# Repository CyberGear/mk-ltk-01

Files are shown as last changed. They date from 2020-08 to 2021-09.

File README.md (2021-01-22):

# Bleeding Charcoal (mk-ltk-01)

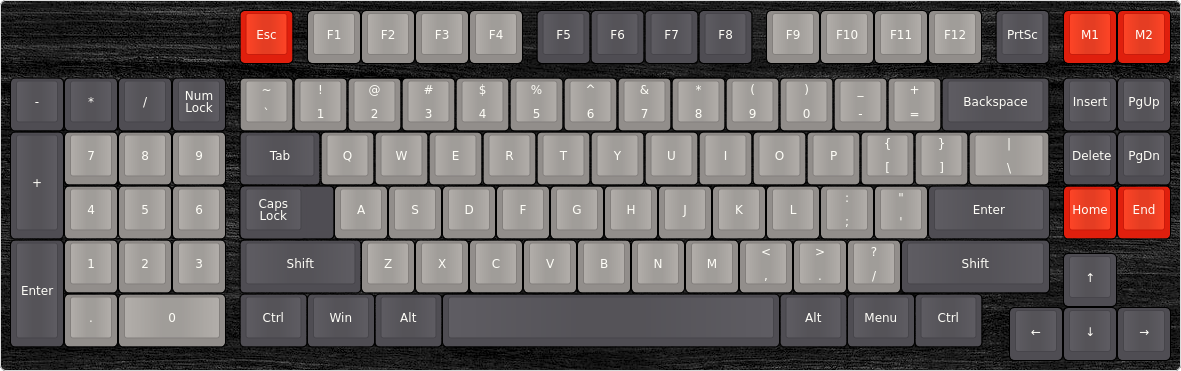
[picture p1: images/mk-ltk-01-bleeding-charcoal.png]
visualisation

[First Idea](./images/mk-ltk-01.png)

## Details
* **Keeb**: Black steel dust painted plate, sandwich case, stained plywood
* **Kaycaps**: [Aliexpress ones](https://www.aliexpress.com/item/1005001285224963.html?spm=a2g0s.9042311.0.0.27424c4dBEbhVW) also custom painted for accent caps
* **Switches**: Gateron brown, Lubed with Krytox 205g0, and filmed.
* **Stabs**: [Aliexpress ones](https://www.aliexpress.com/item/10000249766414.html?spm=a2g0s.9042311.0.0.27424c4dtrbYE2) lubed and cliped a lot :D

## Initial Requirements
* As low prifile as possible
* Reasonable price around 100€ (failed! 170€)
* NOT flat profile keycaps
* Tactile
* Left side num pad
* Stardart layout (keycaps wise)
* Make most space for mouse withour loosing functionality (on the right)

## Tools
* http://www.keyboard-layout-editor.com
* http://builder.swillkb.com/
* https://kbfirmware.com/
* https://noroadsleft.github.io/kbf_qmk_converter/

## Decisions made
* Sandwich case (stained plywood and painted black steel)
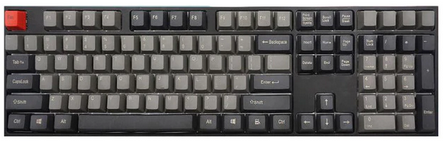
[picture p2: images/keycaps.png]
OEM keycaps
*  
  Unfortunatelly to high for low profile switches
* Diodes 1N4148
* Gateron Brown
* Plate mounted stabs from Aliexpress
* Krytox GPL 205 G0
* Switch Films
* Teensy 2.0++

## Progress

Metal parts :) 

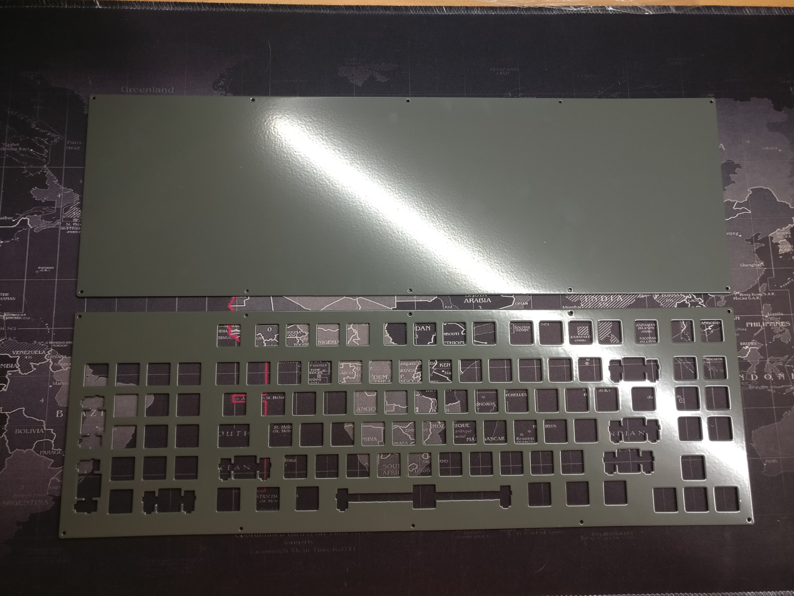
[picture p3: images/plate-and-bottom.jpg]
Plates


Put foam for sound dampening (legacy acrylic frame)

With foam

Plywood case V1

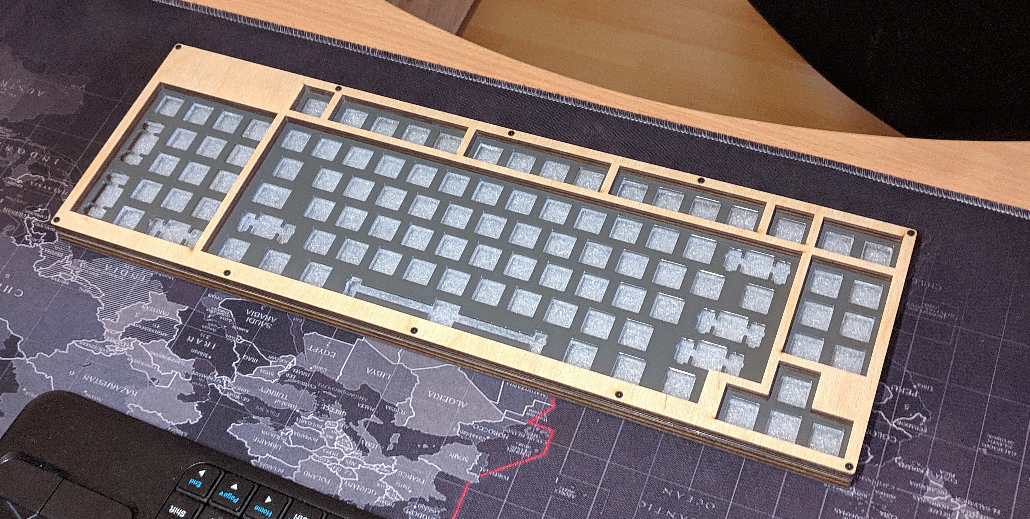
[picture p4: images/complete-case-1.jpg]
Complete case !


Wrist rest :D 

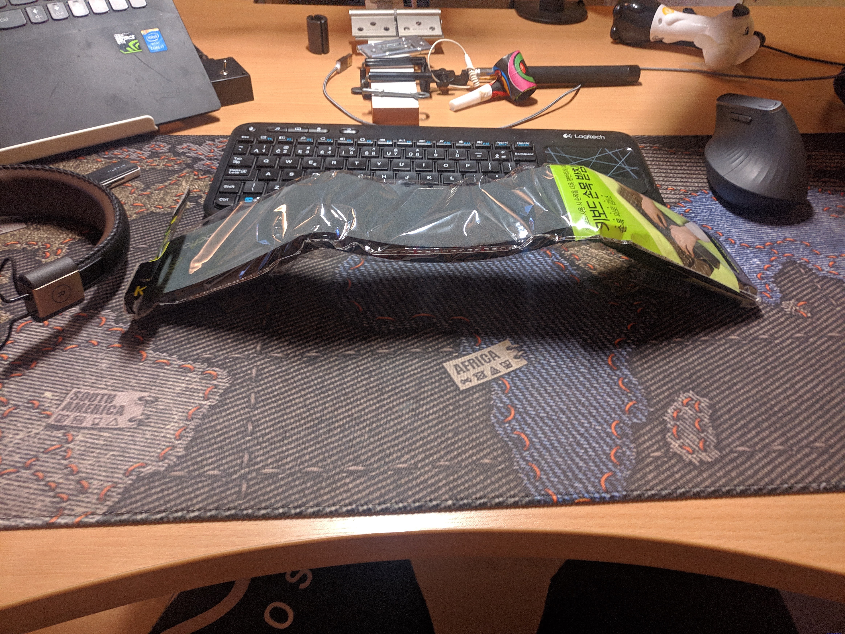
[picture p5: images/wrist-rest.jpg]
Wrist rest


New desk mat

Desk mat

Lubing and filling switches

Lube progress

Fit test "naked"

Nude fit test

Fit test full case

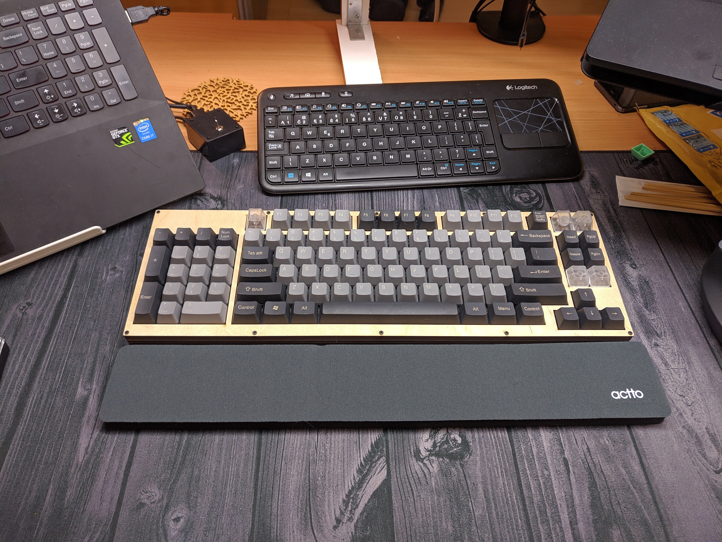
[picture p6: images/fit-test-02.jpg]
Fit test


Screwless top

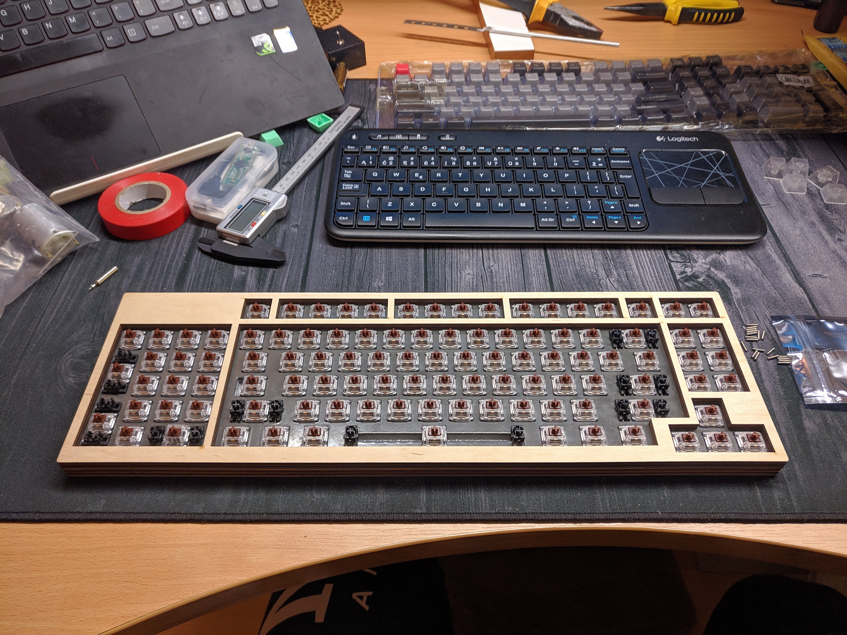
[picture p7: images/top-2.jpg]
Top 2


USB type-C cutout

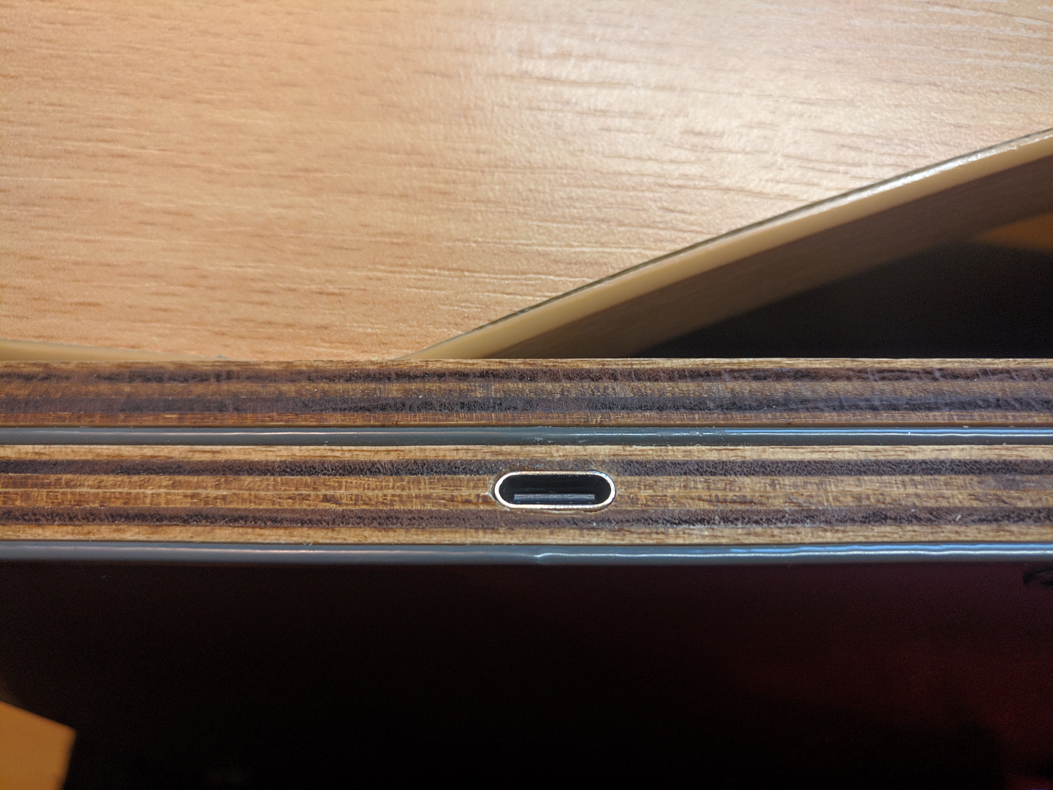
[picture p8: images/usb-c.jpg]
usb-c


Switch matrix ([mirrored](./images/switch-matrix-mirror.png))

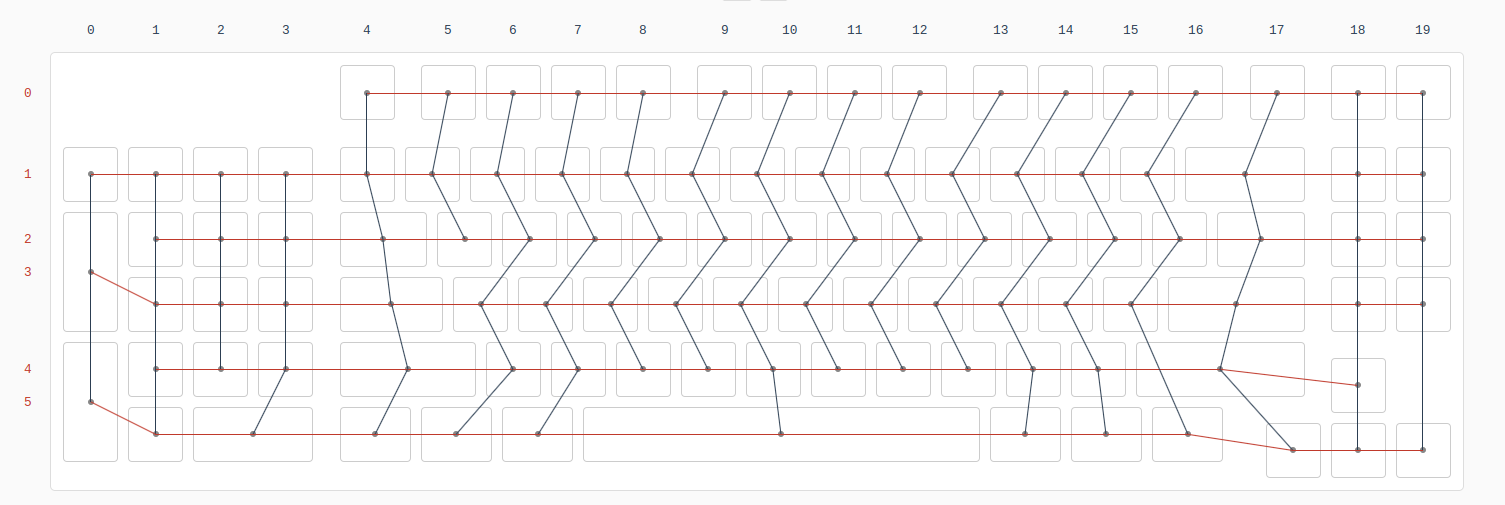
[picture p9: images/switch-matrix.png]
Switch matrix


Wiring

wiring

Usb type-c Integration

usb type-c

More foam

more foam

Total foam

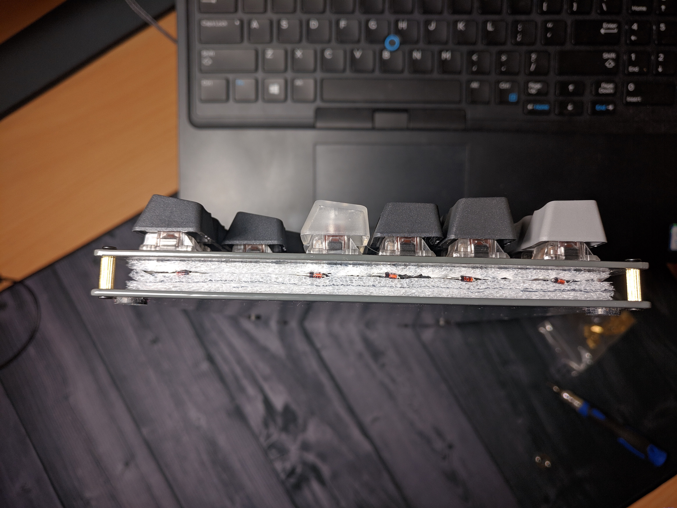
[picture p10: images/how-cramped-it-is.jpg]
total foam


Suprisingly Simple Adjustable Legs

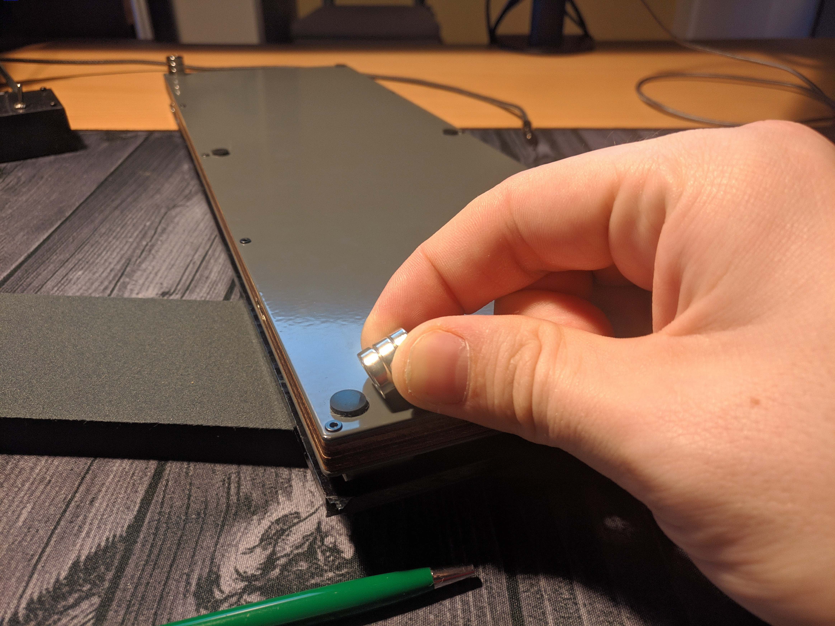
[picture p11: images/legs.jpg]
legs


Custom Spray Painted Keycaps

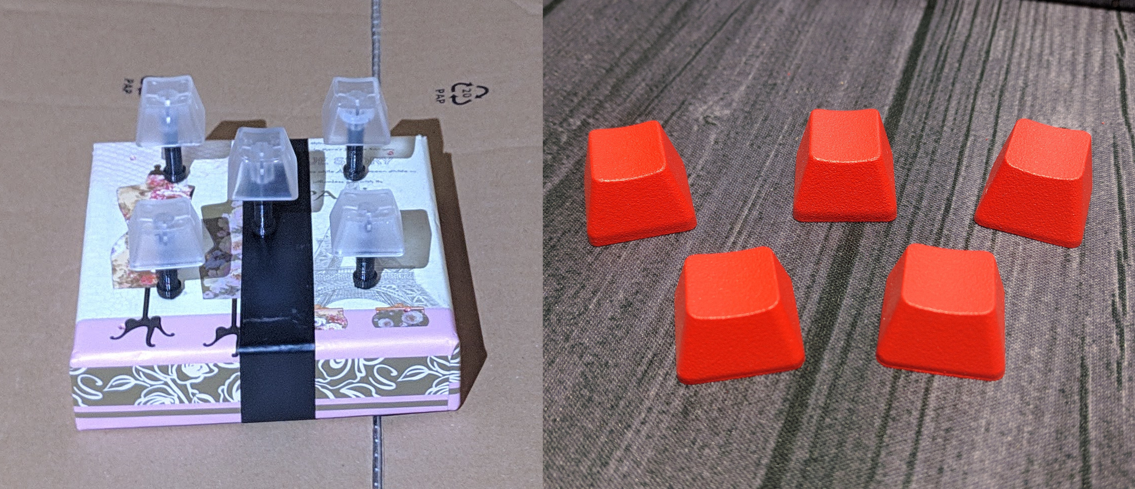
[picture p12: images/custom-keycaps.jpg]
Keycaps


Stained plywood finish

finish

Wire

wire

RESULT

Keeb

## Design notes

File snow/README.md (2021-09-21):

# Kit contents

1. *Plate* - dust painted aluminum
2. *PCB* - also white
3. *Bottom plate* - dust painted steel
4. *USB socket* - fits in one of those cuts in PCB
5. *Socket soldering template* - to help to solder it straight
6. *4 small rubber feet*

# Features

1. Left ten keys layout (southpaw layout) 
2. Intelligently mirrored num pan layout 
3. PCB features:
    1. Supports MX switches 
    2. Supports kailh hot-swappable sockets 
    3. Supports thru-hole diods 
    4. Supports surface mount diodes 

# Required additional parts

1. Teensy ® ++ 2.0
2. Full set of keycaps (recommend flat layout, because of 'Home' and 'End' possitions)
4. Full set of stabilizers 
    1. Plate mounted works out of the box
    2. PCB mounted requires addition filing of switch plate :/ 
5. 108 x MX switches
6. 108 x 1N4148 diods
7. 20 x M2 screws
8. 10 x 9mm M2 spacers (if You remove mini USB from teensy)
9. USB Type-C cable

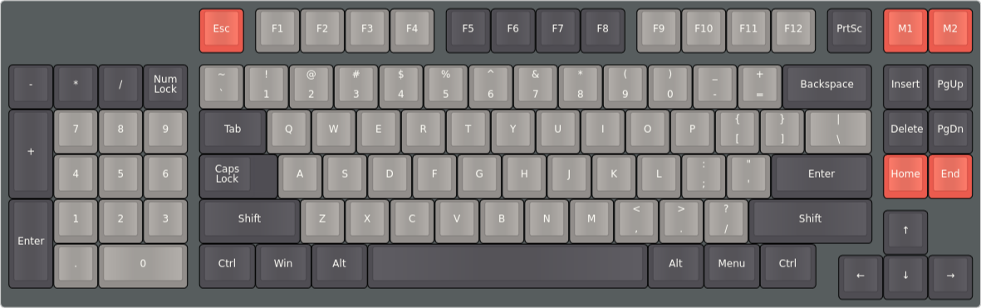
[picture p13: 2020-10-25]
images/mk-ltk-01.png

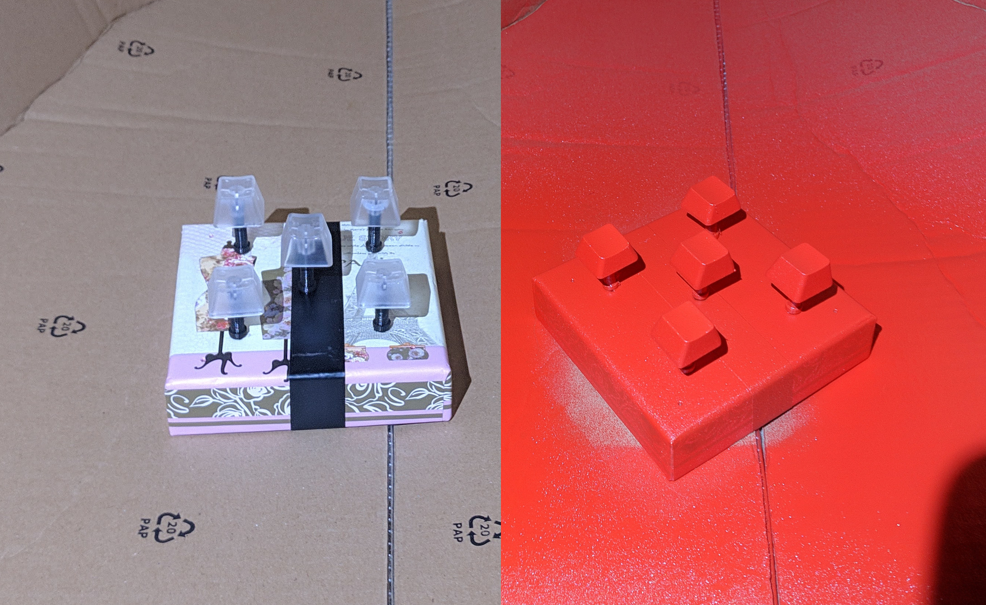
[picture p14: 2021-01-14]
images/keycap-paint-job.jpg

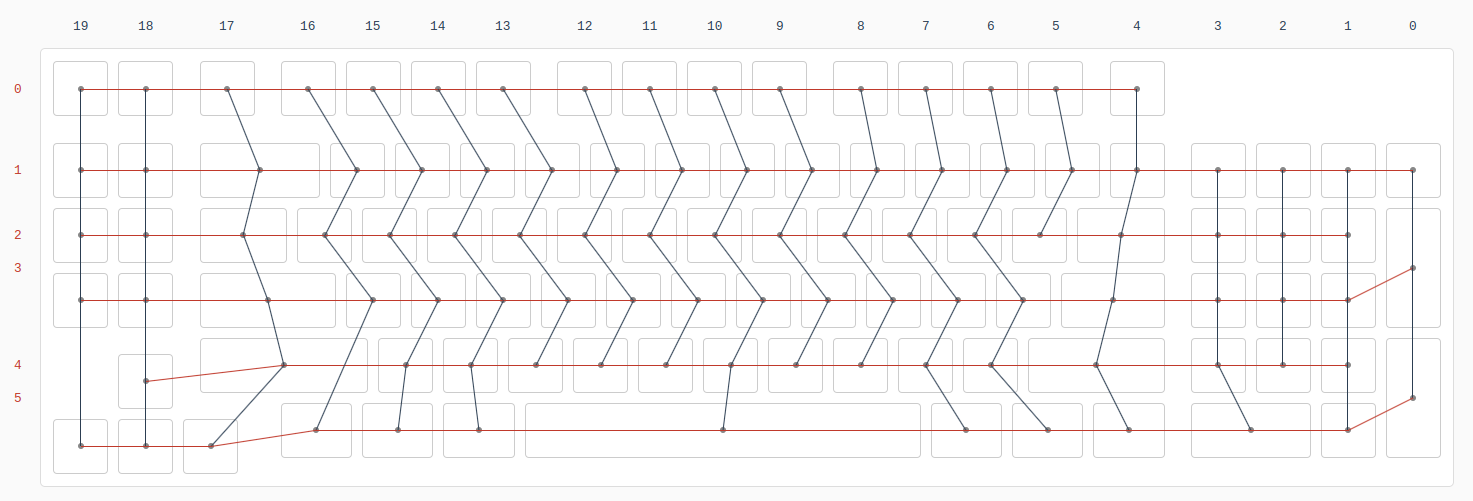
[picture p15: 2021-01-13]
images/switch-matrix-mirror.png

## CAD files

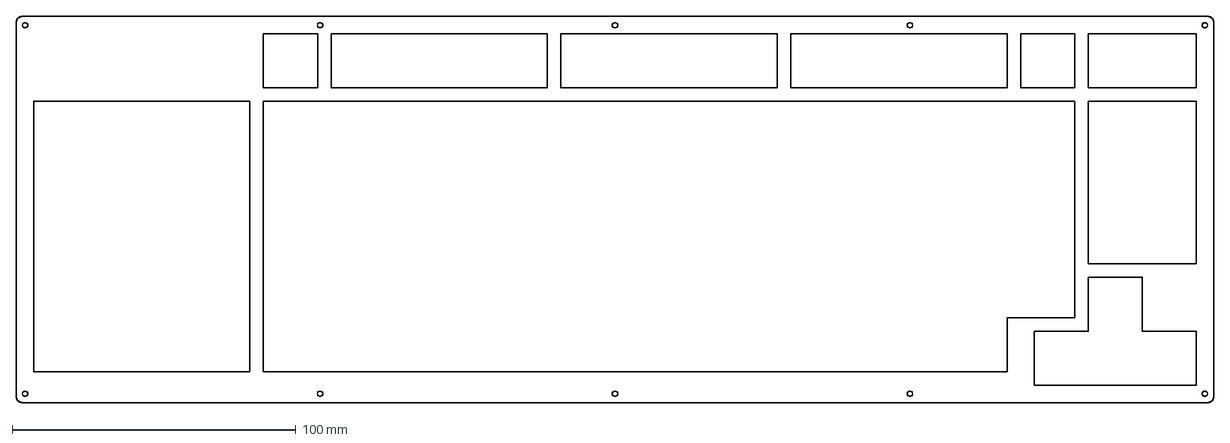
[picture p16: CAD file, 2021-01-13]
sandwich case/mk-ltk-01_top_02_with_holes.dxf
421.8 x 136.0 mm

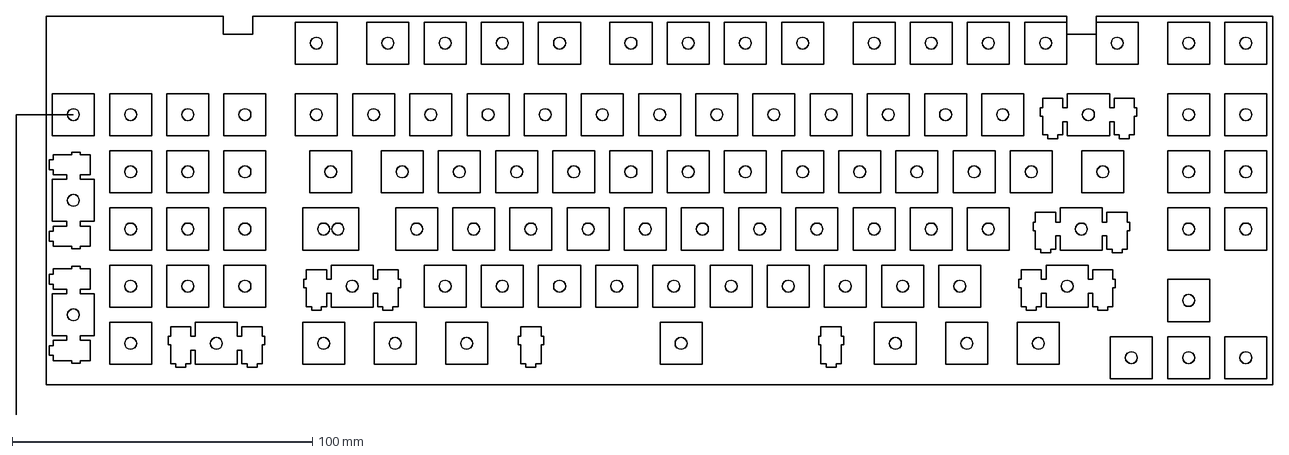
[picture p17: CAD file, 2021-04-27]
snow/onesided-palte.dxf
418.6 x 132.8 mm

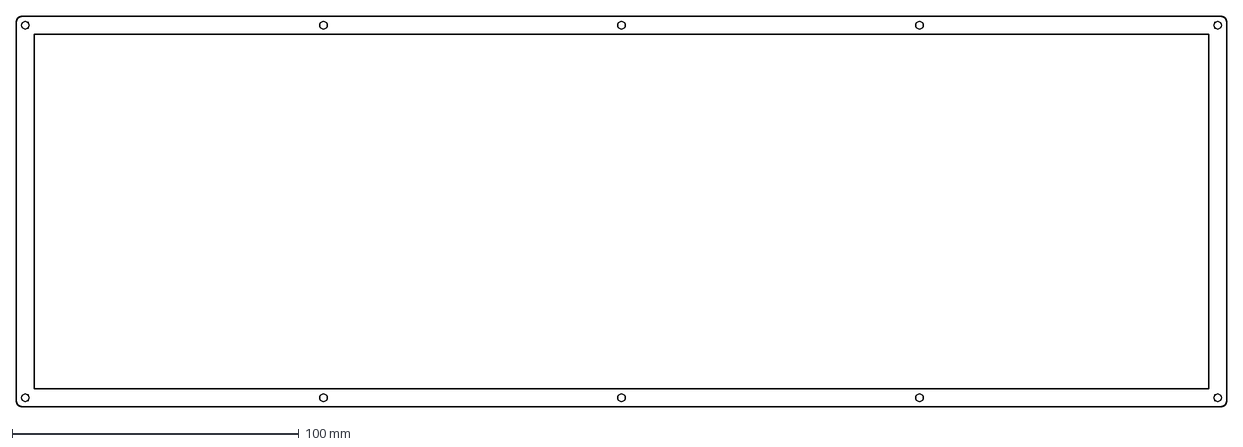
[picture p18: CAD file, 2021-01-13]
sandwich case/mk-ltk-01_closed_02.dxf
421.8 x 136.0 mm

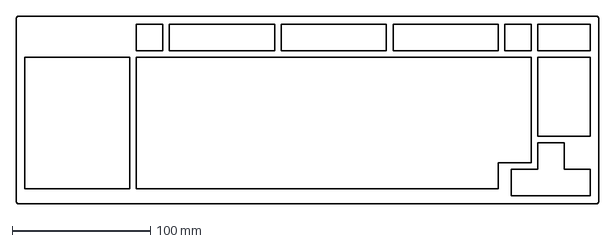
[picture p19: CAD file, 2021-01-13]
sandwich case/mk-ltk-01_top_02.dxf
421.8 x 136.0 mm

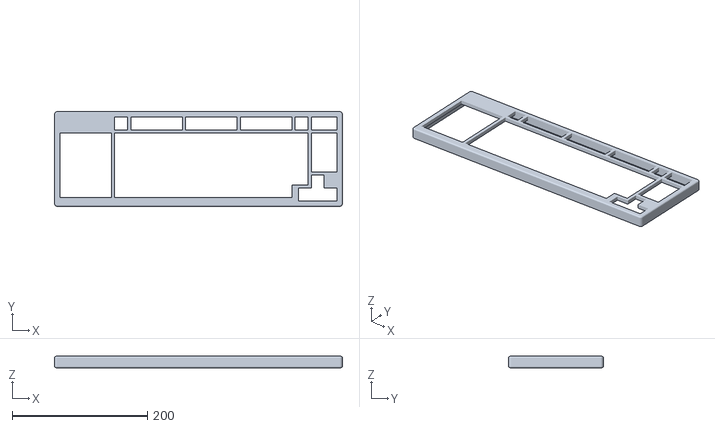
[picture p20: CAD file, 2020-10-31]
sandwich case/mk-ltk-01_top.stl
425.6 x 139.8 x 17.0

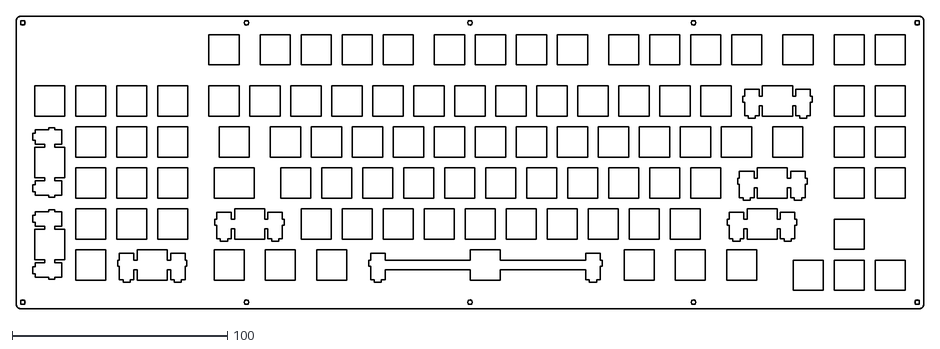
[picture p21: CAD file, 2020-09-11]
sandwich case/mk-ltk-01_switch.dxf
421.6 x 135.8

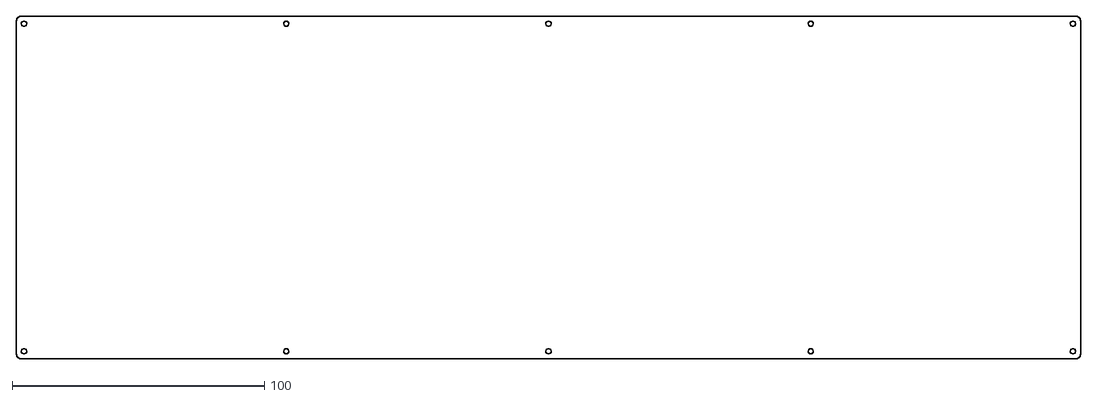
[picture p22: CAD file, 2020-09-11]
sandwich case/mk-ltk-01_bottom.dxf
421.6 x 135.8

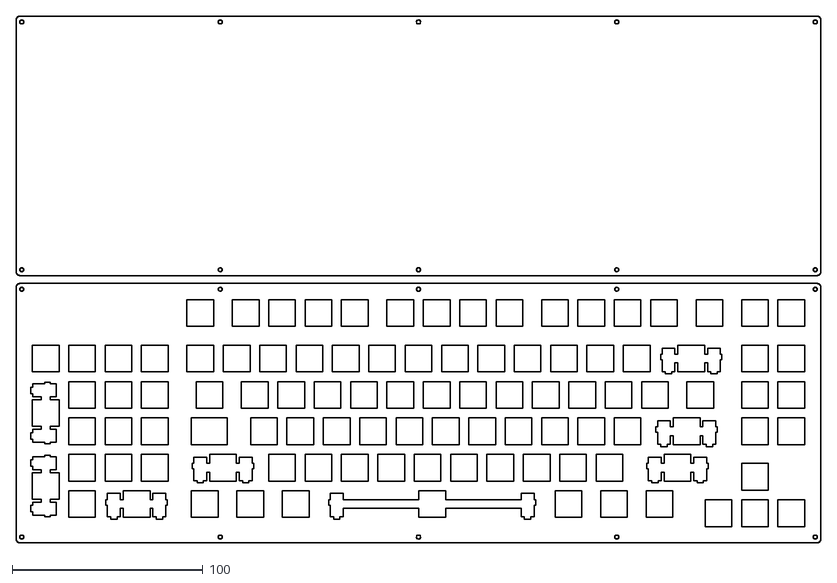
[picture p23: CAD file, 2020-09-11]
sandwich case/mk-ltk-01_switch_bottom.dxf
421.6 x 275.8

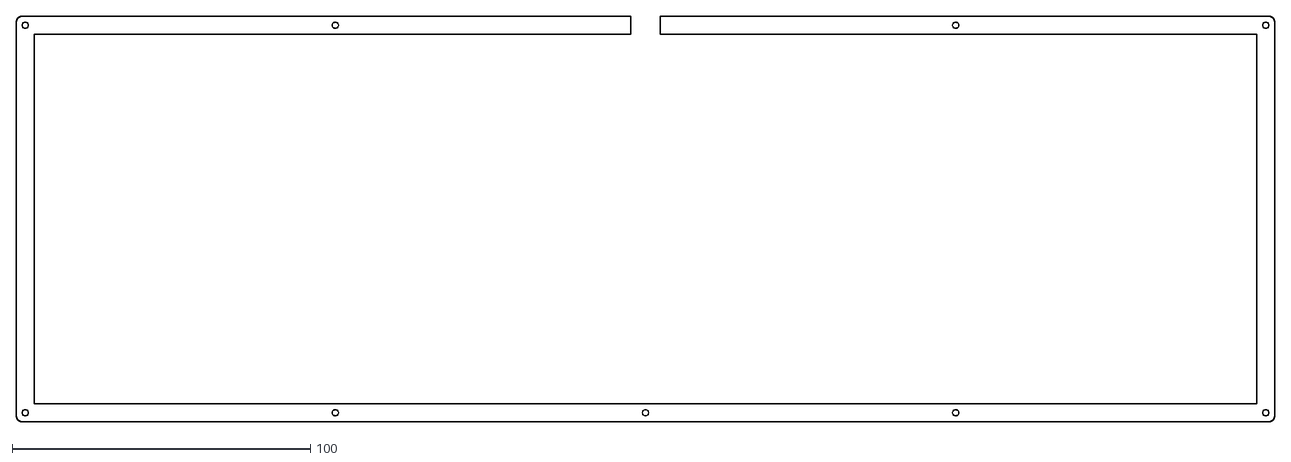
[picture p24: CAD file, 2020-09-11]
sandwich case/mk-ltk-01_open.dxf
421.6 x 135.8

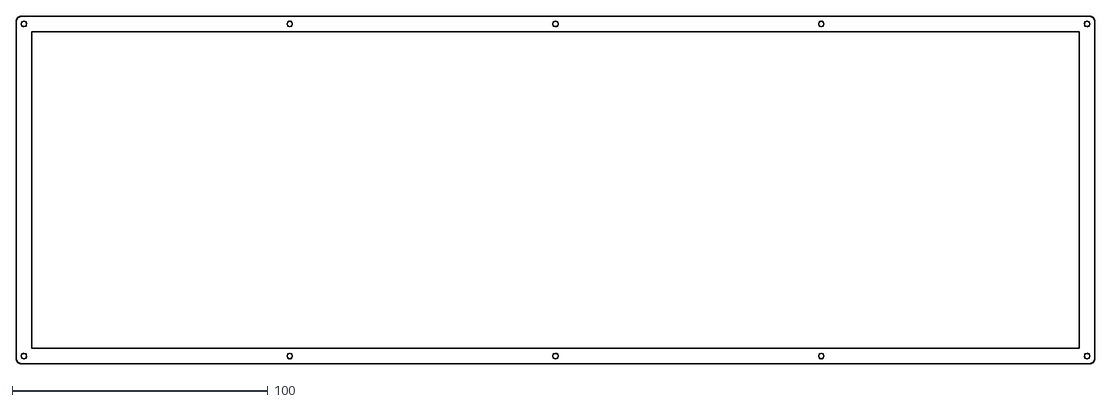
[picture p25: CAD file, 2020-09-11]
sandwich case/mk-ltk-01_closed.dxf
421.6 x 135.8

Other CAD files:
sandwich case/mk-ltk-01_case-cover.FCStd
sandwich case/mk-ltk-01_top.dxf

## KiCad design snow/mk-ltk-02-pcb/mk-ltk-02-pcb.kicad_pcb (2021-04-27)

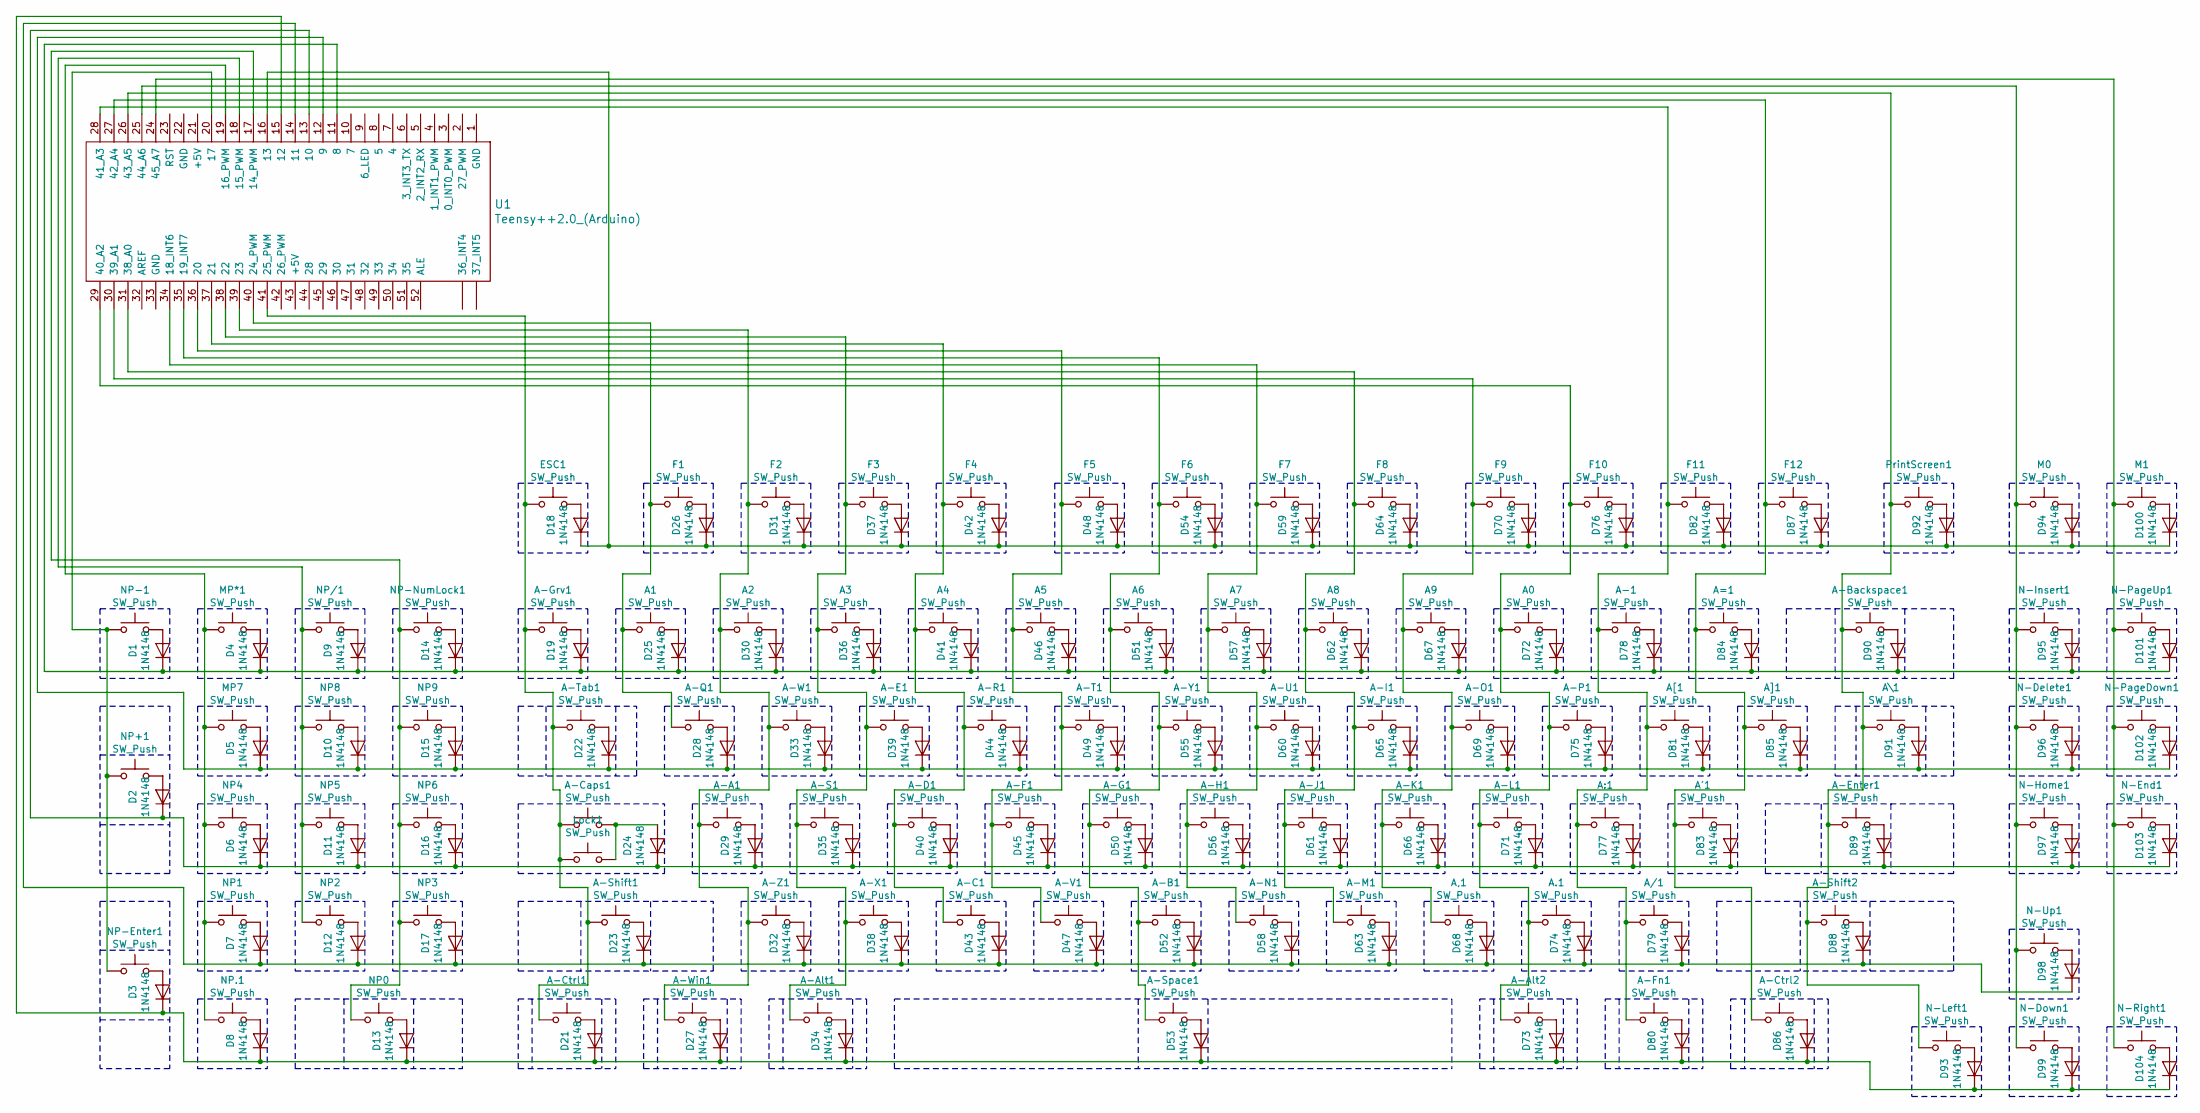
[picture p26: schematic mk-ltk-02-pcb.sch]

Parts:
A0, A1, A2, A3, A4, A5, A6, A7, A8, A9, A.1: SW_Push; Kailh_socket_MX_optional
A'1: SW_Push; Kailh_socket_MX_optional
A,1: SW_Push; Kailh_socket_MX_optional
A-1: SW_Push; Kailh_socket_MX_optional
A-A1: SW_Push; Kailh_socket_MX_optional
A-Alt1, A-Alt2: SW_Push; Kailh_socket_MX_optional
A-B1: SW_Push; Kailh_socket_MX_optional
A-Backspace1: SW_Push; Kailh_socket_MX_optional
A-C1: SW_Push; Kailh_socket_MX_optional
A-Caps1: SW_Push; Kailh_socket_MX_optional
A-Ctrl1, A-Ctrl2: SW_Push; Kailh_socket_MX_optional
A-D1: SW_Push; Kailh_socket_MX_optional
A-E1: SW_Push; Kailh_socket_MX_optional
A-Enter1: SW_Push; Kailh_socket_MX_optional
A-F1: SW_Push; Kailh_socket_MX_optional
A-Fn1: SW_Push; Kailh_socket_MX_optional
A-G1: SW_Push; Kailh_socket_MX_optional
A-Grv1: SW_Push; Kailh_socket_MX_optional
A-H1: SW_Push; Kailh_socket_MX_optional
A-I1: SW_Push; Kailh_socket_MX_optional
A-J1: SW_Push; Kailh_socket_MX_optional
A-K1: SW_Push; Kailh_socket_MX_optional
A-L1: SW_Push; Kailh_socket_MX_optional
A-M1: SW_Push; Kailh_socket_MX_optional
A-N1: SW_Push; Kailh_socket_MX_optional
A-O1: SW_Push; Kailh_socket_MX_optional
A-P1: SW_Push; Kailh_socket_MX_optional
A-Q1: SW_Push; Kailh_socket_MX_optional
A-R1: SW_Push; Kailh_socket_MX_optional
A-S1: SW_Push; Kailh_socket_MX_optional
A-Shift1, A-Shift2: SW_Push; Kailh_socket_MX_optional
A-Space1: SW_Push; Kailh_socket_MX_optional
A-T1: SW_Push; Kailh_socket_MX_optional
A-Tab1: SW_Push; Kailh_socket_MX_optional
A-U1: SW_Push; Kailh_socket_MX_optional
A-V1: SW_Push; Kailh_socket_MX_optional
A-W1: SW_Push; Kailh_socket_MX_optional
A-Win1: SW_Push; Kailh_socket_MX_optional
A-X1: SW_Push; Kailh_socket_MX_optional
A-Y1: SW_Push; Kailh_socket_MX_optional
A-Z1: SW_Push; Kailh_socket_MX_optional
A/1: SW_Push; Kailh_socket_MX_optional
A:1: SW_Push; Kailh_socket_MX_optional
A=1: SW_Push; Kailh_socket_MX_optional
A[1: SW_Push; Kailh_socket_MX_optional
A\1: SW_Push; Kailh_socket_MX_optional
A]1: SW_Push; Kailh_socket_MX_optional
D1, D2, D3, D4, D5, D6, D7, D8, D9, D10, D11, D12, D13, D14, D15, D16, D17, D18, D19, D21, D22, D23, D24, D25, D26, D27, D28, D29, D30, D31, D32, D33, D34, D35, D36, D37, D38, D39, D40, D41, D42, D43, D44, D45, D46, D47, D48, D49, D50, D51, D52, D53, D54, D55, D56, D57, D58, D59, D60, D61, D62, D63, D64, D65, D66, D67, D68, D69, D70, D71, D72, D73, D74, D75, D76, D77, D78, D79, D80, D81, D82, D83, D84, D85, D86, D87, D88, D89, D90, D91, D92, D93, D94, D95, D96, D97, D98, D99, D100, D101, D102, D103, D104: 1N4148; Diode-smd-tht
ESC1: SW_Push; Kailh_socket_MX_optional
F1, F2, F3, F4, F5, F6, F7, F8, F9, F10, F11, F12: SW_Push; Kailh_socket_MX_optional
Lock1: SW_Push; Kailh_socket_MX_optional
M0, M1: SW_Push; Kailh_socket_MX_optional
MP7: SW_Push; Kailh_socket_MX_optional
MP*1: SW_Push; Kailh_socket_MX_optional
N-Delete1: SW_Push; Kailh_socket_MX_optional
N-Down1: SW_Push; Kailh_socket_MX_optional
N-End1: SW_Push; Kailh_socket_MX_optional
N-Home1: SW_Push; Kailh_socket_MX_optional
N-Insert1: SW_Push; Kailh_socket_MX_optional
N-Left1: SW_Push; Kailh_socket_MX_optional
N-PageDown1: SW_Push; Kailh_socket_MX_optional
N-PageUp1: SW_Push; Kailh_socket_MX_optional
N-Right1: SW_Push; Kailh_socket_MX_optional
N-Up1: SW_Push; Kailh_socket_MX_optional
NP0, NP1, NP2, NP3, NP4, NP5, NP6, NP8, NP9, NP.1: SW_Push; Kailh_socket_MX_optional
NP+1: SW_Push; Kailh_socket_MX_optional
NP-1: SW_Push; Kailh_socket_MX_optional
NP-Enter1: SW_Push; Kailh_socket_MX_optional
NP-NumLock1: SW_Push; Kailh_socket_MX_optional
NP/1: SW_Push; Kailh_socket_MX_optional
PrintScreen1: SW_Push; Kailh_socket_MX_optional
U1: Teensy++2.0_(Arduino); Teensy2.0++

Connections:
unnamed: A0.2, D72.2 (A)
unnamed: A1.2, D25.2 (A)
unnamed: A2.2, D30.2 (A)
unnamed: A3.2, D36.2 (A)
unnamed: A4.2, D41.2 (A)
unnamed: A5.2, D46.2 (A)
unnamed: A6.2, D51.2 (A)
unnamed: A7.2, D57.2 (A)
unnamed: A8.2, D62.2 (A)
unnamed: A9.2, D67.2 (A)
unnamed: A'1.1, A-Ctrl2.1, A=1.1, A]1.1, F12.1, U1.27 (42_A4)
unnamed: A'1.2, D83.2 (A)
unnamed: A9.1, A,1.1, A-K1.1, A-O1.1, F9.1, U1.30 (39_A1)
unnamed: A,1.2, D68.2 (A)
unnamed: A-1.1, A-Fn1.1, A/1.1, A:1.1, A[1.1, F11.1, U1.28 (41_A3)
unnamed: A-1.2, D78.2 (A)
unnamed: A2.1, A-A1.1, A-W1.1, A-Win1.1, A-Z1.1, F2.1, U1.39 (23)
unnamed: A-A1.2, D29.2 (A)
unnamed: A3.1, A-Alt1.1, A-E1.1, A-S1.1, A-X1.1, F3.1, U1.38 (22)
unnamed: A-Alt1.2, D34.2 (A)
unnamed: A0.1, A-Alt2.1, A-L1.1, A-P1.1, A.1.1, F10.1, U1.29 (40_A2)
unnamed: A-Alt2.2, D73.2 (A)
unnamed: A6.1, A-B1.1, A-G1.1, A-Space1.1, A-Y1.1, F6.1, U1.35 (19_INT7)
unnamed: A-B1.2, D52.2 (A)
unnamed: A-Backspace1.1, A-Enter1.1, A-Shift2.1, A\1.1, N-Left1.1, PrintScreen1.1, U1.26 (43_A5)
unnamed: A-Backspace1.2, D90.2 (A)
unnamed: A4.1, A-C1.1, A-D1.1, A-R1.1, F4.1, U1.37 (21)
unnamed: A-C1.2, D43.2 (A)
unnamed: A-Caps1.1, A-Ctrl1.1, A-Grv1.1, A-Shift1.1, A-Tab1.1, ESC1.1, Lock1.1, U1.41 (25_PWM)
unnamed: A-Caps1.2, D24.2 (A), Lock1.2
unnamed: A-Ctrl1.2, D21.2 (A)
unnamed: A-Ctrl2.2, D86.2 (A)
unnamed: A-D1.2, D40.2 (A)
unnamed: A-E1.2, D39.2 (A)
unnamed: A-Enter1.2, D89.2 (A)
unnamed: A5.1, A-F1.1, A-T1.1, A-V1.1, F5.1, U1.36 (20)
unnamed: A-F1.2, D45.2 (A)
unnamed: A-Fn1.2, D80.2 (A)
unnamed: A-G1.2, D50.2 (A)
unnamed: A-Grv1.2, D19.2 (A)
unnamed: A7.1, A-H1.1, A-N1.1, A-U1.1, F7.1, U1.34 (18_INT6)
unnamed: A-H1.2, D56.2 (A)
unnamed: A8.1, A-I1.1, A-J1.1, A-M1.1, F8.1, U1.31 (38_A0)
unnamed: A-I1.2, D65.2 (A)
unnamed: A-J1.2, D61.2 (A)
unnamed: A-K1.2, D66.2 (A)
unnamed: A-L1.2, D71.2 (A)
unnamed: A-M1.2, D63.2 (A)
unnamed: A-N1.2, D58.2 (A)
unnamed: A-O1.2, D69.2 (A)
unnamed: A-P1.2, D75.2 (A)
unnamed: A1.1, A-Q1.1, F1.1, U1.40 (24_PWM)
unnamed: A-Q1.2, D28.2 (A)
unnamed: A-R1.2, D44.2 (A)
unnamed: A-S1.2, D35.2 (A)
unnamed: A-Shift1.2, D23.2 (A)
unnamed: A-Shift2.2, D88.2 (A)
unnamed: A-Space1.2, D53.2 (A)
unnamed: A-T1.2, D49.2 (A)
unnamed: A-Tab1.2, D22.2 (A)
unnamed: A-U1.2, D60.2 (A)
unnamed: A-V1.2, D47.2 (A)
unnamed: A-W1.2, D33.2 (A)
unnamed: A-Win1.2, D27.2 (A)
unnamed: A-X1.2, D38.2 (A)
unnamed: A-Y1.2, D55.2 (A)
unnamed: A-Z1.2, D32.2 (A)
unnamed: A.1.2, D74.2 (A)
unnamed: A/1.2, D79.2 (A)
unnamed: A:1.2, D77.2 (A)
unnamed: A=1.2, D84.2 (A)
unnamed: A[1.2, D81.2 (A)
unnamed: A\1.2, D91.2 (A)
unnamed: A]1.2, D85.2 (A)
unnamed: D1.1 (K), D4.1 (K), D9.1 (K), D14.1 (K), D19.1 (K), D25.1 (K), D30.1 (K), D36.1 (K), D41.1 (K), D46.1 (K), D51.1 (K), D57.1 (K), D62.1 (K), D67.1 (K), D72.1 (K), D78.1 (K), D84.1 (K), D90.1 (K), D95.1 (K), D101.1 (K), U1.11 (8)
unnamed: D1.2 (A), NP-1.2
unnamed: D2.2 (A), NP+1.2
unnamed: D3.2 (A), NP-Enter1.2
unnamed: D4.2 (A), MP*1.2
unnamed: D5.2 (A), MP7.2
unnamed: D6.2 (A), NP4.2
unnamed: D7.2 (A), NP1.2
unnamed: D8.2 (A), NP.1.2
unnamed: D9.2 (A), NP/1.2
unnamed: D5.1 (K), D10.1 (K), D15.1 (K), D22.1 (K), D28.1 (K), D33.1 (K), D39.1 (K), D44.1 (K), D49.1 (K), D55.1 (K), D60.1 (K), D65.1 (K), D69.1 (K), D75.1 (K), D81.1 (K), D85.1 (K), D91.1 (K), D96.1 (K), D102.1 (K), U1.12 (9)
unnamed: D10.2 (A), NP8.2
unnamed: D11.2 (A), NP5.2
unnamed: D7.1 (K), D12.1 (K), D17.1 (K), D23.1 (K), D32.1 (K), D38.1 (K), D43.1 (K), D47.1 (K), D52.1 (K), D58.1 (K), D63.1 (K), D68.1 (K), D74.1 (K), D79.1 (K), D88.1 (K), D98.1 (K), U1.14 (11)
unnamed: D12.2 (A), NP2.2
unnamed: D13.2 (A), NP0.2
unnamed: D14.2 (A), NP-NumLock1.2
unnamed: D15.2 (A), NP9.2
unnamed: D16.2 (A), NP6.2
unnamed: D17.2 (A), NP3.2
unnamed: D18.2 (A), ESC1.2
unnamed: D26.2 (A), F1.2
unnamed: D31.2 (A), F2.2
unnamed: D37.2 (A), F3.2
unnamed: D42.2 (A), F4.2
unnamed: D48.2 (A), F5.2
unnamed: D54.2 (A), F6.2
unnamed: D59.2 (A), F7.2
unnamed: D64.2 (A), F8.2
unnamed: D70.2 (A), F9.2
unnamed: D76.2 (A), F10.2
unnamed: D82.2 (A), F11.2
unnamed: D87.2 (A), F12.2
unnamed: D92.2 (A), PrintScreen1.2
unnamed: D93.2 (A), N-Left1.2
unnamed: D94.2 (A), M0.2
unnamed: D95.2 (A), N-Insert1.2
unnamed: D96.2 (A), N-Delete1.2
unnamed: D97.2 (A), N-Home1.2
unnamed: D98.2 (A), N-Up1.2
unnamed: D99.2 (A), N-Down1.2
unnamed: D18.1 (K), D26.1 (K), D31.1 (K), D37.1 (K), D42.1 (K), D48.1 (K), D54.1 (K), D59.1 (K), D64.1 (K), D70.1 (K), D76.1 (K), D82.1 (K), D87.1 (K), D92.1 (K), D94.1 (K), D100.1 (K), U1.16 (13)
unnamed: D100.2 (A), M1.2
unnamed: D101.2 (A), N-PageUp1.2
unnamed: D102.2 (A), N-PageDown1.2
unnamed: D2.1 (K), D6.1 (K), D11.1 (K), D16.1 (K), D24.1 (K), D29.1 (K), D35.1 (K), D40.1 (K), D45.1 (K), D50.1 (K), D56.1 (K), D61.1 (K), D66.1 (K), D71.1 (K), D77.1 (K), D83.1 (K), D89.1 (K), D97.1 (K), D103.1 (K), U1.13 (10)
unnamed: D103.2 (A), N-End1.2
unnamed: D3.1 (K), D8.1 (K), D13.1 (K), D21.1 (K), D27.1 (K), D34.1 (K), D53.1 (K), D73.1 (K), D80.1 (K), D86.1 (K), D93.1 (K), D99.1 (K), D104.1 (K), U1.15 (12)
unnamed: D104.2 (A), N-Right1.2
unnamed: M0.1, N-Delete1.1, N-Down1.1, N-Home1.1, N-Insert1.1, N-Up1.1, U1.25 (44_A6)
unnamed: M1.1, N-End1.1, N-PageDown1.1, N-PageUp1.1, N-Right1.1, U1.24 (45_A7)
unnamed: MP7.1, MP*1.1, NP1.1, NP4.1, NP.1.1, U1.19 (16_PWM)
unnamed: NP+1.1, NP-1.1, NP-Enter1.1, U1.20 (17)
unnamed: NP0.1, NP3.1, NP6.1, NP9.1, NP-NumLock1.1, U1.17 (14_PWM)
unnamed: NP2.1, NP5.1, NP8.1, NP/1.1, U1.18 (15_PWM)

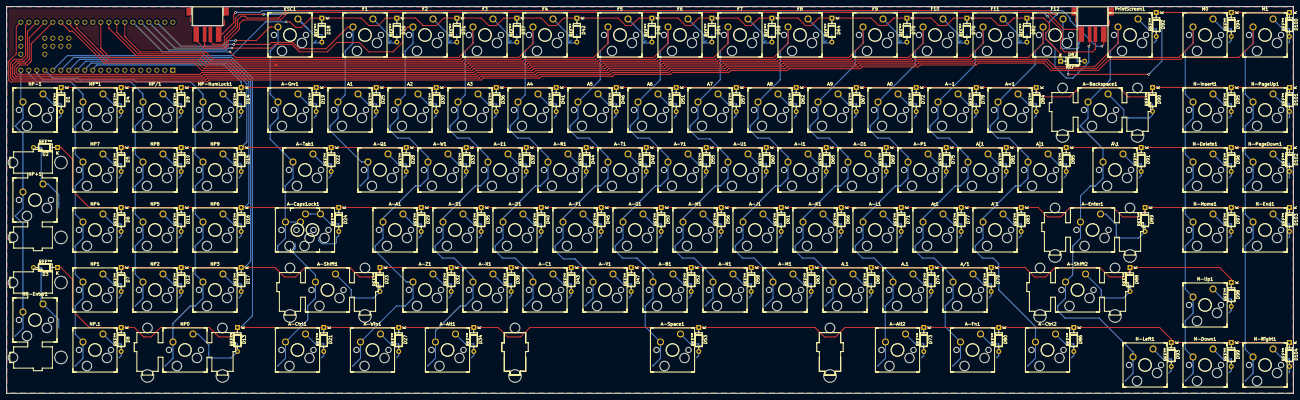
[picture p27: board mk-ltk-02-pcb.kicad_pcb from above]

Board: 2 copper layers, 408.5 x 122.8 mm, 208 parts (1 on the bottom side), 129 nets.

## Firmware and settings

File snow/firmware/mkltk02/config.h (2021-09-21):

/* Copyright 2021 REPLACE_WITH_YOUR_NAME
 *
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
 * You should have received a copy of the GNU General Public License
 * along with this program.  If not, see <http://www.gnu.org/licenses/>.
 */

#pragma once

#include "config_common.h"

/* USB Device descriptor parameter */
#define VENDOR_ID       0xFEED
#define PRODUCT_ID      0x0000
#define DEVICE_VER      0x0001
#define MANUFACTURER    CyberGear
#define PRODUCT         mk-ltk-02

#define MATRIX_ROWS 6
#define MATRIX_COLS 20

#define MATRIX_ROW_PINS { C3, E0, E1, C0, C1, C2 }
#define MATRIX_COL_PINS { C7, C6, C5, C4, B5, B4, B3, B2, B1, B0, E7, E6, F0, F1, F2, F3, F4, F5, F6, F7 }
 
#define DIODE_DIRECTION COL2ROW

#define TAP_CODE_DELAY 10

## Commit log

2020-08-29 update switch options
2020-09-11 add sandwich case files
    [mk-ltk_switch_and_bottom.dxf]
2020-09-11 reupload case files
    [mk-ltk-01_bottom.dxf, mk-ltk-01_closed.dxf, mk-ltk-01_open.dxf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]
2020-10-26 update top and closed layers
    [mk-ltk-01_top.dxf]
2020-10-31 add v1 top 3d model
    [mk-ltk-01_top.stl]
2021-01-13 rearanging with latest project 1
    [mk-ltk-01_case-cover.FCStd, mk-ltk-01_closed_02.dxf, mk-ltk-01_top_02.dxf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]
2021-04-24 add pcb project v1
    [mk-ltk-02-pcb-B_Cu.gbr, mk-ltk-02-pcb-B_Mask.gbr, mk-ltk-02-pcb-B_Paste.gbr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]
2021-04-27 add usb cutouts and ground plane
    [mk-ltk-02-pcb.kicad_pcb, onesided-palte.dxf]

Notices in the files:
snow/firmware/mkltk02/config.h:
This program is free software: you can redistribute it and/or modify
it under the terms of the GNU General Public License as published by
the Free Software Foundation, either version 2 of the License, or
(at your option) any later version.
